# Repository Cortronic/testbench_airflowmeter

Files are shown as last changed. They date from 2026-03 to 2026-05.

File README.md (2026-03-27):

# Airflow Calibration Test Bench

<p align="left">
  
</p>  
<p align="left">
  
</p>

A high-precision, modular 125mm wind tunnel designed for the calibration and validation of airflow meters. This rig serves as the absolute reference for the [Zero-Pressure Airflow Meter project](https://github.com/Cortronic/airflowmeter).

## 1. Project Overview

The Calibration Test Bench establishes a known, stable volumetric flow rate ($m^3/h$) by drawing air through a laboratory-grade Venturi nozzle. It allows the user to set a fixed fan power and use the resulting flow as a "Golden Standard" to calibrate secondary measurement devices.

---

## 2. Hardware & Electronics

The rig uses an **ESP32-WROOM** to process environmental data and differential pressure, calculating the reference flow in real-time. To eliminate extreme static underpressure when testing restricted valves, the rig utilizes a coordinated dual-fan setup.

### Components

* **Sensor 1:** SDP810-500PA (Differential pressure across the Venturi).
* **Sensor 2:** SDP810-125PA (Differential pressure at the inlet of the Venturi).
* **Sensor 3:** BME280 (Ambient temperature, humidity, and barometric pressure).
* **Display:** 1.3" OLED (SH1106) for real-time reference data.
* **Encoder:** Rotary encode with pushbutton for speedcontrol and menu navigation.
* **Actuator:** 2 x Arctic S12038-8K High-Static Pressure Fan (12V PWM).

### ESP32 Pinout

| Component | Function | ESP32 GPIO | Notes |
| --- | --- | --- | --- |
| **I2C Bus 0** | Data / Clock | **21 / 22** | BME280, OLED, SDP810 (Venturi) |
| **I2C Bus 1** | Data / Clock | **25 / 26** | SDP810 (Balance-Pressure Sensor) |
| **Encoder** | CLK / DT / SW | **18, 19, 5** | Speed control,  Menu & Calibration |
| **PWM Pull Fan** | Speed Control | **27** | 25kHz PWM signal |
| **PWM Push Fan** | Balance Control | **14** | 25kHz PWM signal |

---

## 3. Mechanical Design

### Modular 125mm Construction

The rig is built from 125mm diameter sections, optimized for standard ventilation parts:

1. **Inlet Interface:** A 500x500mm mounting panel for airextract valves.
2. **Push Drive Section:** A high-power server fan capable of overcoming the resistance of filters and valves.
3. **Flow Conditioning:** Dual honeycomb straighteners to eliminate swirl and ensure a laminar profile before the Venturi.
4. **The Venturi Core:** A 3-part 3D-printed assembly ($D=120\text{mm}$, $d=90\text{mm}$).
5. **Pressure Sensing:** Dual piezometric (averaging) rings at the inlet and throat for stable readings.
6. **Pull Drive Section:** A high-power server fan capable of overcoming the resistance of filters and valves.
7. **Outlet Interface:** A 500x500mm mounting panel for airsupply valves.

---

## 4. Active Static Pressure Balancing
The Test Bench features an advanced "Active Balance" control loop to ensure measurement linearity regardless of inlet restriction.

* **Primary Loop (Flow Control):** The Exhaust (Pull) fan is set to a specific PWM or RPM to achieve the target flow rate.
* **Secondary Loop (Pressure Balance):** A dedicated SDP810 sensor monitors the static pressure difference between the Venturi inlet and the ambient room.
* **Active Compensation:** A PID controller adjusts the Inlet (Push) fan in real-time. If a restrictive valve causes a pressure drop, the Push fan increases power until the internal static pressure returns to 0.0 Pa (Atmospheric Neutral).

**Result:** The Venturi operates in a "Stagnation-Free" zone, eliminating the "Negative Delta-P" phenomenon and ensuring laboratory-grade accuracy even at >90% valve restriction.

---

## 5. Calibration Physics

The reference flow $Q$ is calculated using the ISO 5167 standard principles, corrected for the actual air density at the time of measurement.

### Air Density ($\rho$)

Density is calculated using the **Magnus-Tetens** formula to account for water vapor:

$$\rho = \frac{p_{dry}}{R_d \cdot T} + \frac{p_{vapor}}{R_v \cdot T}$$

### Volumetric Flow ($Q$)

$$\text{Reference } Q = 3600 \cdot C_d \cdot A_{throat} \cdot \sqrt{\frac{2 \cdot \Delta P}{\rho \cdot (1 - \beta^4)}}$$

The discharge coefficient ($C_d$) is determined during initial rig validation (typically 0.975).

---

## 6. Usage: Calibrating the Flow Meter

This rig is designed to be used in conjunction with the **Zero-Pressure Airflow Meter** interactive calibration modes.

### Calibration Workflow:

1. **Establish Reference:** Run the Test Bench fan at a fixed power (e.g., 50%) and note the reference flow (e.g., $120.0 \text{ m}^3/h$).
2. **Attach Device Under Test (DUT):** Place the Zero-Pressure Flow Meter against the rig's inlet.
3. **Zero-Compensation:** Use the Flow Meter's `Tune Zero-Comp` menu to shift its setpoint until the Test Bench returns to exactly $120.0 \text{ m}^3/h$.
4. **Flow Gain:** Use the `Tune Flow` menu to match the Flow Meter's display to the Test Bench's reference value.

### Traceability & Validation
  
The reference flow of this Test Bench is validated against a calibrated Testo 420.
1. A multi-point measurement was performed across the full PWM range of the fan.
2. The Discharge Coefficient ($C_d$) was empirically determined by comparing the Venturi $\Delta P$ to the calibrated reference flow.
3. This ensures that the Test Bench acts as a traceable "Golden Standard" for secondary devices.

---

## 7. Manufacturing Notes

* **Material:** PETG (0.2mm layer height).
* **Assembly:** Parts are flanged for easy airtight coupling. The Venturi sections are bonded with epoxy to prevent leaks at the pressure rings.
* **Precision:** The internal surface of the Venturi should be sanded or printed with high precision to maintain a consistent $C_d$.

---

## License

MIT License - Created for the open-source ventilation community.

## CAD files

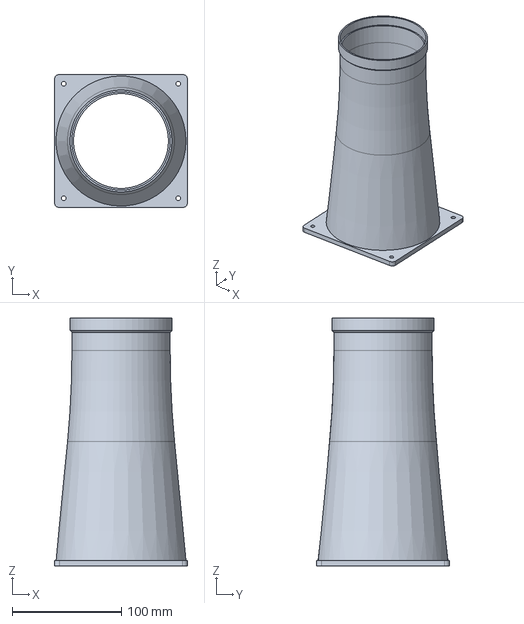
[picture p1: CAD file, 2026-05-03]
freecad/outlet120mm.FCStd
122.0 x 122.0 x 227.4 mm

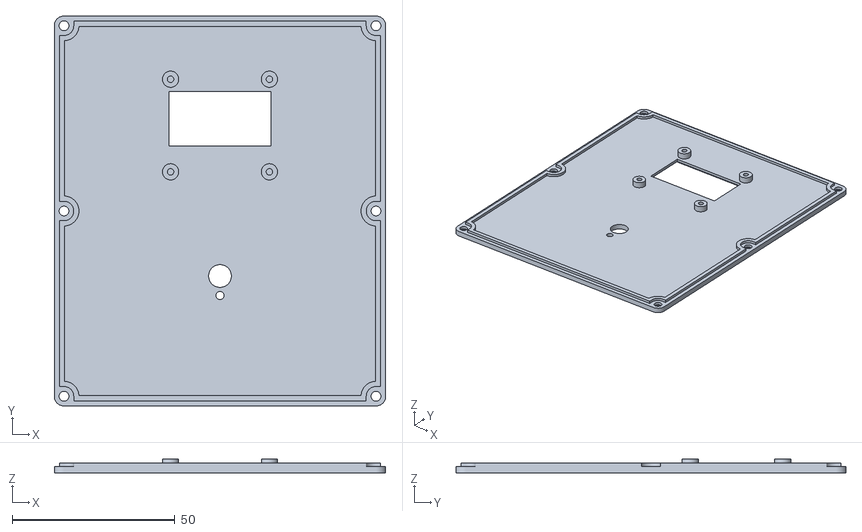
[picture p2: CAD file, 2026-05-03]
stl/case_testbench_body_lid.stl
102.0 x 120.0 x 4.30

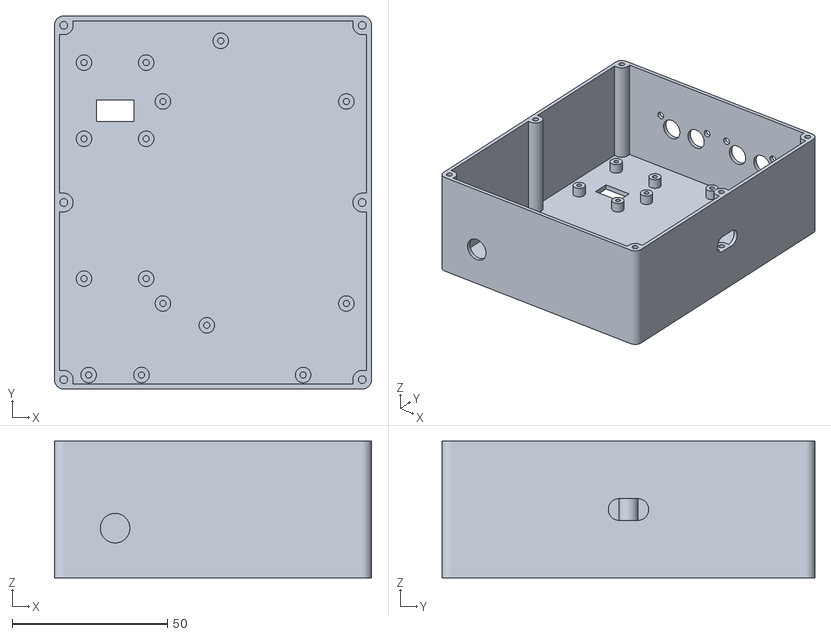
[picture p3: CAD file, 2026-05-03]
stl/case_testbench_body_case.stl
102.0 x 120.0 x 44.0

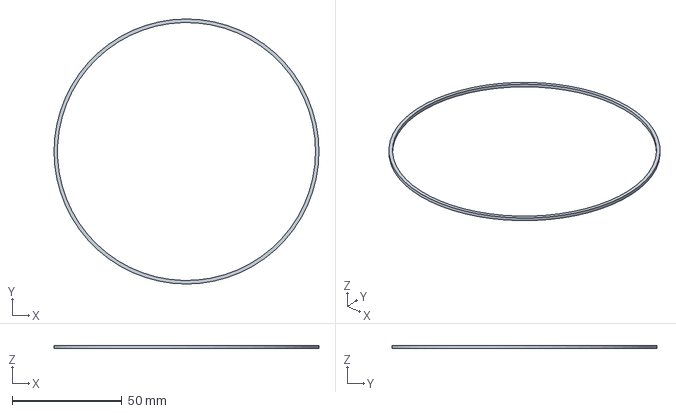
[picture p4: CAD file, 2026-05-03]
freecad/gasket.FCStd
120.8 x 120.8 x 1.40 mm

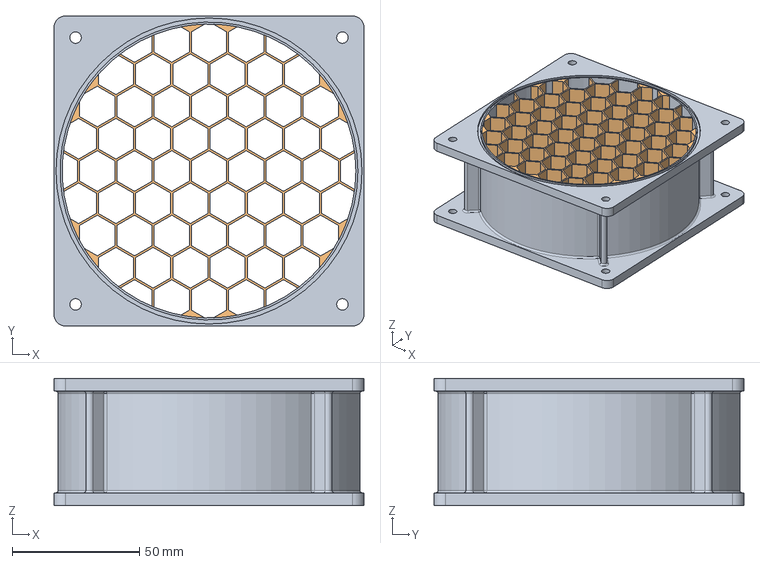
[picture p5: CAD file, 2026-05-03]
freecad/flowstraitener.FCStd
122.0 x 122.0 x 50.0 mm
BodyInlet
BodyHoneycomb

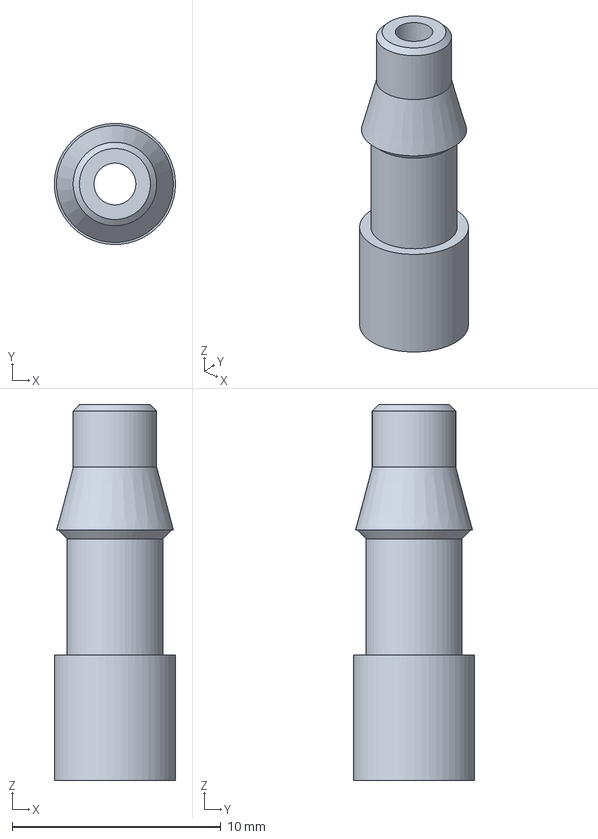
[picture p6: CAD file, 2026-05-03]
freecad/hosebarb.FCStd
5.79 x 5.80 x 18.0 mm

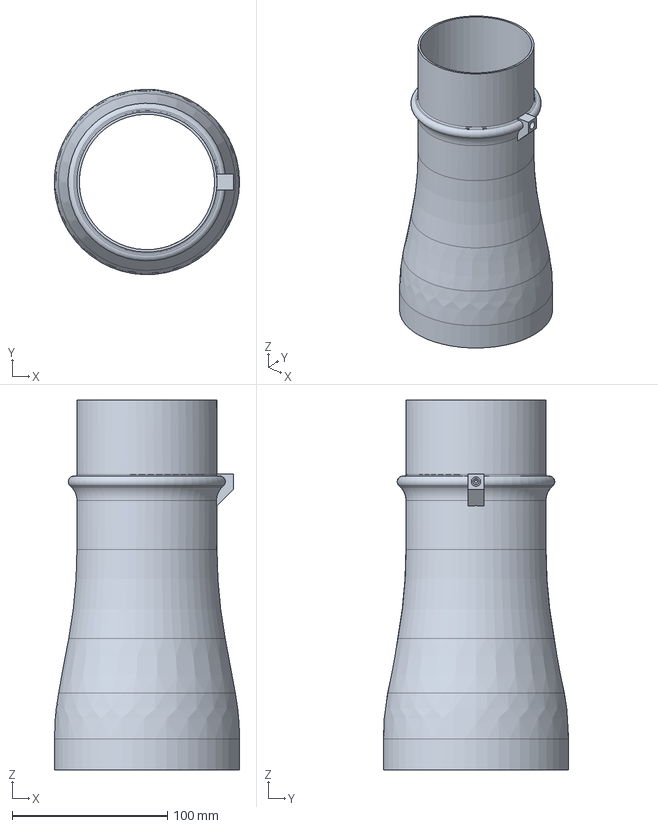
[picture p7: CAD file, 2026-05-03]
freecad/venturi120mm.FCStd
119.1 x 119.1 x 238.0 mm

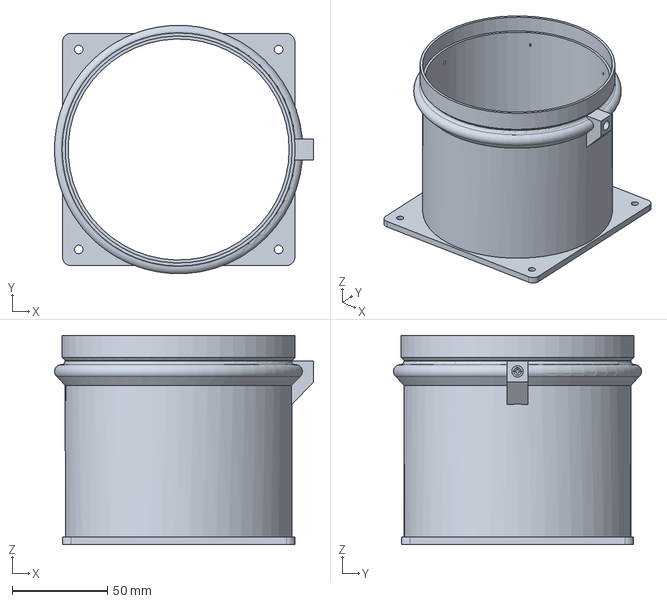
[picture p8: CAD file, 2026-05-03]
freecad/inlet120mm.FCStd
136.0 x 130.3 x 110.0 mm

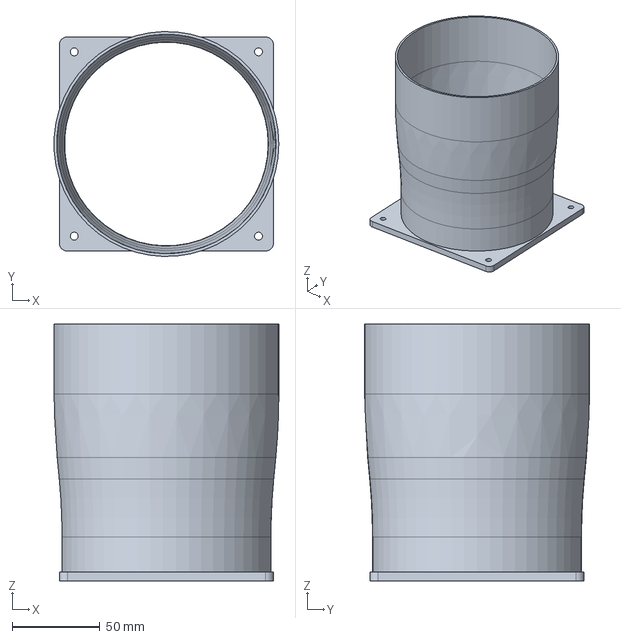
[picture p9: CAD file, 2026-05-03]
freecad/adaper120-125mm.FCStd
128.1 x 128.1 x 146.5 mm

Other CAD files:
freecad/case_testbench.FCStd
stl/adaper120-125mm.stl
stl/flowstraitener.stl
stl/gasket.stl
stl/hosebarb.stl
stl/outlet_120mm.stl

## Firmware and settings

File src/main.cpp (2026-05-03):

#include "main.h"
#include "venturi.h"
#include "fan.h"
#include "PidController.h"
#include <Arduino.h>
#include <Wire.h>
#include <Preferences.h>
#include <AiEsp32RotaryEncoder.h>
#include <AiEsp32RotaryEncoderNumberSelector.h>
#include <SensirionCore.h>
#include <SensirionI2CSdp.h>
#include <Adafruit_SH110X.h>
#include <Fonts/Picopixel.h>
#include <Adafruit_Sensor.h>
#include <Adafruit_BME280.h>
#include <Smoothed.h>

// Pin definitions
const int FAN_ON_PIN  = 32;
const int FAN_PULL_PWM_PIN = 27;
const int FAN_PUSH_PWM_PIN = 14;
const int FAN_PULL_TACHO_PIN = 34;
const int FAN_PUSH_TACHO_PIN = 35;

//I2C pin definitions
const int I2C_SDA0_PIN = 21;
const int I2C_SCL0_PIN = 22;
const int I2C_SDA1_PIN = 25;
const int I2C_SCL1_PIN = 26;

// Display
const int I2C_ADDRESS_DISPLAY = 0x3C;
const int I2C_ADDRESS_BME280  = 0x76;
const int I2C_ADDRESS_SDP810  = 0x25;

// Rotary encoder
const int ROTARY_ENCODER_A_PIN = 18;
const int ROTARY_ENCODER_B_PIN = 19;
const int ROTARY_ENCODER_BUTTON_PIN = 5;
const int ROTARY_ENCODER_STEPS = 4;

// PWM settings
const int PWM_PULL_FAN_CHAN = LEDC_CHANNEL_0;
const int PWM_PUSH_FAN_CHAN = LEDC_CHANNEL_1;
const int PWM_FREQ = 25000;    // 25 kHz frequency for computer fans
const int PWM_RESOLUTION = 10; // 10-bit resolution (0-1023)
const int PWM_DITHER_RESOLUTION = 2; // 2-bit resolution for dithering (0-3)

// tachometer
volatile uint32_t tachoFanPulseCycles;
volatile uint32_t tachoPushFanPulseCount;
volatile uint32_t tachoPullFanPulseCount;
volatile uint32_t tachoPullFanRPM = 0;
volatile uint32_t tachoPushFanRPM = 0;

// Venturi
Venturi venturi;

Fan pullFan(FAN_PULL_PWM_PIN, PWM_PULL_FAN_CHAN, PWM_FREQ, PWM_RESOLUTION, PWM_DITHER_RESOLUTION);
Fan pushFan(FAN_PUSH_PWM_PIN, PWM_PUSH_FAN_CHAN, PWM_FREQ, PWM_RESOLUTION, PWM_DITHER_RESOLUTION);

//paramaters for button
const unsigned long shortPressAfterMiliseconds = 50;   // how long short press shoud be.
                                                       // Do not set too low to avoid bouncing (false press events).
const unsigned long longPressAfterMiliseconds = 1000;  // how long long press shoud be.

AiEsp32RotaryEncoder *rotaryEncoder = new AiEsp32RotaryEncoder(ROTARY_ENCODER_A_PIN, ROTARY_ENCODER_B_PIN,
  ROTARY_ENCODER_BUTTON_PIN, -1, ROTARY_ENCODER_STEPS, false);
AiEsp32RotaryEncoderNumberSelector numberSelector = AiEsp32RotaryEncoderNumberSelector();

Preferences preferences;

Smoothed<float> balancePressure;
Smoothed<float> pressureAbsolute;
Smoothed<float> temperatureAmbient;
Smoothed<float> humidityAmbient;
Smoothed<float> calibration;

// Twee hardware I2C bussen
TwoWire I2C_A = TwoWire(0);
TwoWire I2C_B = TwoWire(1);

SensirionI2CSdp sdpVenturi;
SensirionI2CSdp sdpBalance;

// Initialize the OLED display using Wire library
// ADDRESS, SDA, SCL  -  SDA and SCL usually populate automatically
// based on your board's pins_arduino.h 
// e.g. https://github.com/esp8266/Arduino/blob/master/variants/nodemcu/pins_arduino.h
// SH1106Wire      display(I2C_ADDRESS_DISPLAY, I2C_SDA0_PIN, I2C_SCL0_PIN, GEOMETRY_128_64);
Adafruit_SH1106G display(128, 64, &I2C_A);
Adafruit_BME280  bme280;     // I2C

hw_timer_t *timer0 = nullptr;
volatile bool ms20_passed = false;

FollowFanType followFanType = FOLLOW_PULL_FAN;
ModeType modeType = MT_OPERATION;
PidTuneType pidTuneType = PID_TUNE_NONE;
OperatingMode operatingMode = OM_SPEED_PULL_FAN;
VenturiConstantsType venturiConstantsType = VENTURI_CONSTANTS_SET_NONE;


double minPidFlowInput = NAN;
double maxPidFlowInput = NAN;
double minPidFlowFilteredInput = NAN;
double maxPidFlowFilteredInput = NAN;
double minPidFlowOutput = NAN;
double maxPidFlowOutput = NAN;

double outputMasterFan = 0.0;
double KpFlow=2, KiFlow=0, KdFlow=0, flowOutputTrendLimit=0.5;
double flowAlpha=0.2, flowBeta=0.02;
PidController pidFlow(KpFlow, KiFlow, KdFlow, 0.02, 0.0, 100.0);

double minPidBalanceInput = NAN;
double maxPidBalanceInput = NAN;
double minPidBalanceFilteredInput = NAN;
double maxPidBalanceFilteredInput = NAN;
double minPidBalanceOutput = NAN;
double maxPidBalanceOutput = NAN;

double outputSlaveFan = 0.0;
double KpBalance = 6, KiBalance = 3, KdBalance = 0, balanceOutputTrendLimit = 0.5;
double balanceAlpha = 0.2, balanceBeta = 0.02;
PidController pidBalance(KpBalance, KiBalance, KdBalance, 0.02, 0.0, 100.0);

float offsetVenturiPressure = 0.0;
float offsetBalancePressure = 0.0;
float lastEncoderOperationValue = 0.0;

static void  setupTachometers();
static void  setupTimer0();
static void  readPressureSensors();
static void  loadPreferences();
static void  setupRotaryEncoder();
static void  setMasterFan(FollowFanType type);
static void  setMasterFanSpeedPercent(float speed);
static void  setSlaveFanSpeedPercent(float speed);
static void  setOperationMode(OperatingMode mode);
static void  initDisplay();
static void  loopRotaryEncoder();
static void  displayMeasurements();
static void  displaySelectMode(ModeType);
static void  displaySelectOperationMode(OperatingMode mode);
static void  displayTextNumber(const char *txt, float);
static void  displayAdjustSensorOffsets(const char *sensor);
static void  displayAdjustSensorOffsetsProgress(int16_t progress);
static void  displaySelectTunePID(PidTuneType type);
static void  displaySelectVenturiConstants(VenturiConstantsType type);
static void  initBME280();
static void  initSDP(SensirionI2CSdp&, TwoWire&);
static void  drawString(int16_t x, int16_t y, const String &text);
//////////////////////////////////////////////////////////////////////////

void setup() {

  Serial.begin(115200);

  Serial.println("\ntestbench_airflowmeter is starting up...");

  // prefent fan from starting up
  pinMode(FAN_ON_PIN, OUTPUT);
  digitalWrite(FAN_ON_PIN, LOW);

  //setupTachometers();

  // load preferences (calibration and PID parameters)
  loadPreferences();

  // setup RotaryEncoder
  setupRotaryEncoder();

  // Setup Fans
  Serial.println("Setup Fans");
  pullFan.begin();
  pushFan.begin();

  // set initial fan speeds to zero
  setMasterFanSpeedPercent(0);
  setSlaveFanSpeedPercent(0);
  delay(1000);

  // Start both I2C busses
  I2C_A.begin(I2C_SDA0_PIN, I2C_SCL0_PIN, 700000);   // SDA, SCL
  I2C_B.begin(I2C_SDA1_PIN, I2C_SCL1_PIN, 100000);

  Serial.println("Setup Display");
  initDisplay();
  delay(500);
  Serial.println("Setup BME280");
  initBME280();
  delay(500);
  Serial.println("Setup SDP810 Venturi");
  initSDP(sdpVenturi, I2C_A);
  delay(500);
  Serial.println("Setup SDP810 Balance");
  initSDP(sdpBalance, I2C_B);
  delay(500);

  Serial.println("setup smoothed average.");
  balancePressure.begin(SMOOTHED_EXPONENTIAL, 10);
  calibration.begin(SMOOTHED_AVERAGE, 200);
  pressureAbsolute.begin(SMOOTHED_AVERAGE, 40);
  humidityAmbient.begin(SMOOTHED_AVERAGE, 40);
  temperatureAmbient.begin(SMOOTHED_AVERAGE, 40);
  delay(500);

  // initialize the Flow PID variables
  Serial.println("turn the PID Flow on.");
  pidFlow.setTunings(KpFlow, KiFlow, KdFlow);
  pidFlow.setOutputLimits(0, 100.0, flowOutputTrendLimit); // Output will be in percentage of max PWM (0-100%)
  pidFlow.setSampleTime(0.02); // 20 ms sample time
  pidFlow.setAlpha(flowAlpha);
  pidFlow.setBeta(flowBeta);
  pidFlow.setOutputTrendLimit(flowOutputTrendLimit);
  delay(500);

  // initialize the Balance PID variables
  Serial.println("turn the PID Balance on.");
  pidBalance.setTunings(KpBalance, KiBalance, KdBalance);
  pidBalance.setOutputLimits(0, 100, balanceOutputTrendLimit); // Output will be in percentage of max PWM (0-100%)
  pidBalance.setSampleTime(0.02); // 20 ms sample time
  pidBalance.setAlpha(balanceAlpha); // Set the alpha parameter for the exponential moving average filter
  pidBalance.setBeta(balanceBeta); // Set the beta parameter for trend estimation
  pidBalance.setOutputTrendLimit(balanceOutputTrendLimit); // Set the trend limit to prevent excessive influence of the trend on the output
  delay(500);

  // get initial measurements from the sensors to populate the smoothed averages and the venturi flow calculation
  bme280.takeForcedMeasurement();
  pressureAbsolute.add(bme280.readPressure());
  temperatureAmbient.add(bme280.readTemperature());
  humidityAmbient.add(bme280.readHumidity());
  venturi.setRho(pressureAbsolute.get(), temperatureAmbient.get(), humidityAmbient.get());

  // Setup timer interrupt for tachometer reading, flow and balance pressure PID loops
  Serial.print("Setup timer interrupt\n");
  setupTimer0();
  delay(500);
  
  Serial.print("\n Setup done...\n\n");
  delay(500);
}
//////////////////////////////////////////////////////////////////////////

void loop() {
  static uint32_t loopcnt = 0;
  static uint32_t last_millis = 0;
  uint32_t now = millis();
  
  // repeated calls are needed to avoid that the display slows down the loop and causes the PID to underperform
  readPressureSensors();

  loopRotaryEncoder();

  // every 100ms
  if (now >= last_millis + 100) {
    last_millis = now;

    readPressureSensors();
    
    // every second
    if (loopcnt % 10 == 0) {

      // Only needed in forced mode! In normal mode, you can remove the next line.
      bme280.takeForcedMeasurement(); // has no effect in normal mode
      readPressureSensors();

      // get the measurements from the BME280
      pressureAbsolute.add(bme280.readPressure()); // Pa
      readPressureSensors();
      temperatureAmbient.add(bme280.readTemperature()); // °C
      readPressureSensors();
      humidityAmbient.add(bme280.readHumidity());
      readPressureSensors();
      
      /* Serial.printf("Flow: %.1f m3/s\n", venturi.getLastFlow());
      Serial.printf("Dutycycle Masterfan: %.1f%%\n", outputMasterFan);
      Serial.printf("Balance Pressure: %.1f Pa\n", balancePressure.get());
      Serial.printf("Dutycycle Slavefan: %.1f%%\n", outputPidBalanceFan);
      readPressureSensors(); // */
    }
    
    // every second
    if (loopcnt % 10 == 0) {
      if (!isnan(minPidFlowFilteredInput)) {
        Serial.printf(
          "flow: %.1fm3/h, %.1fm3/h, %.1fm3/s, %.1fm3/s, %.1f%%, %.1f%%  \r",
          minPidFlowInput,
          maxPidFlowInput,
          minPidFlowFilteredInput,
          maxPidFlowFilteredInput,
          minPidFlowOutput,
          maxPidFlowOutput
        );
        minPidFlowInput = NAN;
        maxPidFlowInput = NAN;
        minPidFlowFilteredInput = NAN;
        maxPidFlowFilteredInput = NAN;
        minPidFlowOutput = NAN;
        maxPidFlowOutput = NAN;
        readPressureSensors();
      }
      if (!isnan(minPidBalanceFilteredInput)) {
        Serial.printf(
          "balance: %.1fpa, %.1fpa, %.2fpa, %.2fpa, %.1f%%, %.1f%%  \r",
          minPidBalanceInput,
          maxPidBalanceInput,
          minPidBalanceFilteredInput,
          maxPidBalanceFilteredInput,
          minPidBalanceOutput,
          maxPidBalanceOutput
        );
        minPidBalanceInput = NAN;
        maxPidBalanceInput = NAN;
        minPidBalanceFilteredInput = NAN;
        maxPidBalanceFilteredInput = NAN;
        minPidBalanceOutput = NAN;
        maxPidBalanceOutput = NAN;
        readPressureSensors();
      }
    }

    // every 2 seconds
    if (loopcnt % 20 == 0) {
      if (modeType == MT_OPERATION 
          || modeType == MT_CAL_FLOW
          || pidTuneType != PID_TUNE_NONE
          || venturiConstantsType != VENTURI_CONSTANTS_SET_NONE
      ) {
        displayMeasurements(); // 42ms
      }
    }

    // every minute
    if (loopcnt % 600 == 0) {
       venturi.setRho(pressureAbsolute.get(), temperatureAmbient.get(), humidityAmbient.get());
       readPressureSensors();
    }

    ++loopcnt;
  }
}
//////////////////////////////////////////////////////////////////////////

// Interrupt Service Routine (ISR)
// IRAM_ATTR places the function in RAM for faster execution
void IRAM_ATTR Timer0_ISR() {
  ms20_passed = true;
  
  pushFan.handleDither(); // Call the handleDither method for the push fan to manage PWM dithering
  pullFan.handleDither(); // Call the handleDither method for the pull fan to manage PWM dithering
  
  // Handle tachometer pulse counting and RPM calculation
  if (--tachoFanPulseCycles == 0) {
    tachoPullFanRPM = tachoPullFanPulseCount * 10;
    tachoPullFanPulseCount = 0;
    tachoPushFanRPM = tachoPushFanPulseCount * 10;
    tachoPushFanPulseCount = 0;
    tachoFanPulseCycles = 150;
  }
}
//////////////////////////////////////////////////////////////////////////

void IRAM_ATTR readEncoder_ISR() {
    rotaryEncoder->readEncoder_ISR();
}
//////////////////////////////////////////////////////////////////////////

void IRAM_ATTR readButton_ISR() {
    rotaryEncoder->readButton_ISR();
}
//////////////////////////////////////////////////////////////////////////

void IRAM_ATTR tachoPullFanPulseCount_ISR() {
  tachoPullFanPulseCount++;
}
//////////////////////////////////////////////////////////////////////////

void IRAM_ATTR tachoPushFanPulseCount_ISR() {
  tachoPushFanPulseCount++;
}
//////////////////////////////////////////////////////////////////////////

static void setupTachometers() {
  tachoPushFanPulseCount = 0;
  tachoPullFanPulseCount = 0;
  tachoFanPulseCycles = 150;
  pinMode(FAN_PULL_TACHO_PIN, INPUT_PULLUP); // GPIO 34
  attachInterrupt(digitalPinToInterrupt(FAN_PULL_TACHO_PIN), tachoPullFanPulseCount_ISR, FALLING);
  pinMode(FAN_PUSH_TACHO_PIN, INPUT_PULLUP); // GPIO 35
  attachInterrupt(digitalPinToInterrupt(FAN_PUSH_TACHO_PIN), tachoPushFanPulseCount_ISR, FALLING);
}
//////////////////////////////////////////////////////////////////////////

static void setupTimer0() {
  // 1. Initialize timer
  //timerBegin(timer_number, divider, countUp)
  // Prescaler 80: 80MHz / 80 = 1MHz (1 microsecond per tick)
  timer0 = timerBegin(0, 80, true);

  // 2. Attach the ISR function
  timerAttachInterrupt(timer0, &Timer0_ISR, true);

  // 3. Set alarm to fire every 20000 ticks (20000 us = 20ms)
  // timerAlarmWrite(timer, microseconds, autoreload)
  timerAlarmWrite(timer0, 20000, true);

  // 4. Enable the alarm
  timerAlarmEnable(timer0);
}
//////////////////////////////////////////////////////////////////////////

static void updateStatisticsPidFlow(float flow) {
  if (isnan(minPidFlowInput) || flow < minPidFlowInput) {
    minPidFlowInput = flow;
  }
  if (isnan(maxPidFlowInput) || flow > maxPidFlowInput) {
    maxPidFlowInput = flow;
  }
  if (isnan(minPidFlowFilteredInput) || pidFlow.getFilteredInput() < minPidFlowFilteredInput) {
    minPidFlowFilteredInput = pidFlow.getFilteredInput();
  }
  if (isnan(maxPidFlowFilteredInput) || pidFlow.getFilteredInput() > maxPidFlowFilteredInput) {
    maxPidFlowFilteredInput = pidFlow.getFilteredInput();
  }
  if (isnan(minPidFlowOutput) || outputMasterFan < minPidFlowOutput) {
    minPidFlowOutput = outputMasterFan;
  }
  if (isnan(maxPidFlowOutput) || outputMasterFan > maxPidFlowOutput) {
    maxPidFlowOutput = outputMasterFan;
  }
}
//////////////////////////////////////////////////////////////////////////

static void updateStatisticsPidBalance(float differentialPressure) {
  if (isnan(minPidBalanceInput) || differentialPressure < minPidBalanceInput) {
    minPidBalanceInput = differentialPressure;
  }
  if (isnan(maxPidBalanceInput) || differentialPressure > maxPidBalanceInput) {
    maxPidBalanceInput = differentialPressure;
  }
  if (isnan(minPidBalanceFilteredInput) || pidBalance.getFilteredInput() < minPidBalanceFilteredInput) {
    minPidBalanceFilteredInput = pidBalance.getFilteredInput();
  }
  if (isnan(maxPidBalanceFilteredInput) || pidBalance.getFilteredInput() > maxPidBalanceFilteredInput) {
    maxPidBalanceFilteredInput = pidBalance.getFilteredInput();
  }
  if (isnan(minPidBalanceOutput) || outputSlaveFan < minPidBalanceOutput) {
    minPidBalanceOutput = outputSlaveFan;
  }
  if (isnan(maxPidBalanceOutput) || outputSlaveFan > maxPidBalanceOutput) {
    maxPidBalanceOutput = outputSlaveFan;
  }
}
//////////////////////////////////////////////////////////////////////////

static void readPressureSensors() {
  
  if (ms20_passed == true) {
    ms20_passed = false;
    float differentialPressure, temperature;

    // 2 ms time to read
    uint16_t error = sdpVenturi.readMeasurement(differentialPressure, temperature);
    if (error) {
      Serial.print("Error trying to execute readMeasurement from Venturi Pressure sensor\n");
      venturi.update(0.0);
    } else {
      differentialPressure -= offsetVenturiPressure;
      float flowVenturi = venturi.update(differentialPressure);
      if (modeType != MT_ADJUST_OFFSETS) {
        if (operatingMode == OM_FLOW_PULL_FAN || operatingMode == OM_FLOW_PUSH_FAN) {
          outputMasterFan = pidFlow.update(flowVenturi);
          setMasterFanSpeedPercent(outputMasterFan);
          if (modeType == MT_TUNE_PID_FLOW) {
            updateStatisticsPidFlow(flowVenturi);
          }
        }
      }
    }

    error = sdpBalance.readMeasurement(differentialPressure, temperature);
    if (error) {
      Serial.print("Error trying to execute readMeasurement from Balance Pressure sensor\n");
      balancePressure.add(0.0);
    } else {
      differentialPressure -= offsetBalancePressure;
      balancePressure.add(differentialPressure);
      outputSlaveFan = pidBalance.update(differentialPressure);
      setSlaveFanSpeedPercent(outputSlaveFan);
      if (modeType == MT_TUNE_PID_BALANCE) {
        updateStatisticsPidBalance(differentialPressure);
      }
    }
  }
}
//////////////////////////////////////////////////////////////////////////

static float getFloat(const char* key, float value = NAN) {
  float f;
  preferences.begin("testbench", false);
  f = preferences.getFloat(key, value);
  preferences.end();
  return f == NAN ? 0.0 : f;
}
//////////////////////////////////////////////////////////////////////////

static void saveFloat(const char* key, float value) {
  preferences.begin("testbench", false);
  preferences.putFloat(key, value);
  preferences.end();
}
//////////////////////////////////////////////////////////////////////////

static void loadPreferences() {
  preferences.begin("testbench", true);

  float inletDiameter = preferences.getFloat(KEY_VENTURI_INLET_DIAMETER, 0.116);
  float throatDiameter = preferences.getFloat(KEY_VENTURI_THROAT_DIAMETER, 0.087);
  float dischargeCoefficient = preferences.getFloat(KEY_VENTURI_CD, 0.975);
  venturi.begin(inletDiameter, throatDiameter, dischargeCoefficient);
  venturi.setSmoothedFlowFactor(preferences.getFloat(KEY_VENTURI_SMOOTHING_FACTOR, 0.02));

  offsetBalancePressure = preferences.getFloat(KEY_OFFSET_BALANCE_PRESSURE_SENSOR, 0.0);
  offsetVenturiPressure = preferences.getFloat(KEY_OFFSET_VENTURI_PRESSURE_SENSOR, 0.0);
  KpFlow =  preferences.getFloat(KEY_KP_FLOW, KpFlow);
  KiFlow =  preferences.getFloat(KEY_KI_FLOW, KiFlow);
  KdFlow =  preferences.getFloat(KEY_KD_FLOW, KdFlow);
  flowAlpha = preferences.getFloat(KEY_ALPHA_FLOW, flowAlpha);
  flowBeta = preferences.getFloat(KEY_BETA_FLOW, flowBeta);
  flowOutputTrendLimit = preferences.getFloat(KEY_TREND_LIMIT_FLOW, flowOutputTrendLimit);
  KpBalance = preferences.getFloat(KEY_KP_BALANCE, KpBalance);
  KiBalance = preferences.getFloat(KEY_KI_BALANCE, KiBalance);
  KdBalance = preferences.getFloat(KEY_KD_BALANCE, KdBalance);
  balanceAlpha = preferences.getFloat(KEY_BALANCE_ALPHA, balanceAlpha);
  balanceBeta = preferences.getFloat(KEY_BALANCE_BETA, balanceBeta);
  balanceOutputTrendLimit = preferences.getFloat(KEY_BALANCE_TREND_LIMIT, balanceOutputTrendLimit);

  preferences.end();
}
//////////////////////////////////////////////////////////////////////////

static void setupRotaryEncoder() {
  rotaryEncoder->begin();
  rotaryEncoder->setup(&readEncoder_ISR, &readButton_ISR);
  numberSelector.attachEncoder(rotaryEncoder);

  // numberSelector.setRange parameters:
  float minValue = 0.0;        // set minimum value for example -12.0
  float maxValue = 100.0;      // set maxinum value for example 12.0
  float step = 0.1;            // set step increment, default 1, can be smaller steps like 0.5 or 10
  bool cycleValues = false;    // set true only if you want going to miminum value after maximum 
  unsigned int decimals = 1;   // set precision - how many decimal places you want, default is 0
  numberSelector.setRange(minValue, maxValue,  step, cycleValues, decimals);
  numberSelector.setValue(0);  // sets initial value
}
//////////////////////////////////////////////////////////////////////////

static void setPullFanSpeed(uint32_t speed) {
  static uint32_t lastspeed = 0xFFFFFFFF;

  if (lastspeed != speed) {
    pullFan.setSpeed(speed);
    if (followFanType == FOLLOW_PULL_FAN) {
      if (speed == 0) {
        digitalWrite(FAN_ON_PIN, LOW);
      } else if (lastspeed == 0) {
        digitalWrite(FAN_ON_PIN, HIGH);
      }
      lastspeed = speed;
    } else {
      lastspeed = 0xFFFFFFFF;
    }
  }
} 
//////////////////////////////////////////////////////////////////////////

static void setPullFanSpeedPercent(float percent) {
  uint16_t speed = (uint16_t)(percent * pullFan.getMaxSpeed() / 100.0);
  setPullFanSpeed(speed);
}
//////////////////////////////////////////////////////////////////////////

static void setPushFanSpeed(uint32_t speed) {
  static uint32_t lastspeed = 0xFFFFFFFF;

  if (lastspeed != speed) {
    pushFan.setSpeed(speed);
    if (followFanType == FOLLOW_PUSH_FAN) {
      if (speed == 0) {
        digitalWrite(FAN_ON_PIN, LOW);
      } else if (lastspeed == 0) {
        digitalWrite(FAN_ON_PIN, HIGH);
      }
      lastspeed = speed;
    } else {
      lastspeed = 0xFFFFFFFF;
    }
 }
} 
//////////////////////////////////////////////////////////////////////////

static void setPushFanSpeedPercent(float percent) {
  uint16_t speed = (uint16_t)(percent * pushFan.getMaxSpeed() / 100.0);
  setPushFanSpeed(speed);
}
//////////////////////////////////////////////////////////////////////////

static void setMasterFanSpeed(uint32_t speed) {
  if (followFanType == FOLLOW_PULL_FAN) {
    setPullFanSpeed(speed);
  } else {
    setPushFanSpeed(speed);
  }
}
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

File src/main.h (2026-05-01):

typedef enum {
  MT_SELECT = 0,
  MT_OPERATION = 1,
  MT_SELECT_OPERATION = 2,
  MT_CAL_FLOW = 3,
  MT_TUNE_PID_FLOW = 4,
  MT_TUNE_PID_BALANCE = 5,
  MT_ADJUST_OFFSETS = 6,
  MT_SET_VENTURI_CONSTANTS = 7,
} ModeType;
extern ModeType modeType;

typedef enum {
  FOLLOW_PULL_FAN = 0,
  FOLLOW_PUSH_FAN = 1,
} FollowFanType;
extern FollowFanType followFanType;

typedef enum {
  OM_SPEED_PULL_FAN = 0,
  OM_SPEED_PUSH_FAN = 1,
  OM_FLOW_PULL_FAN = 2,
  OM_FLOW_PUSH_FAN = 3,
} OperatingMode;
extern OperatingMode operatingMode;

typedef enum {
  PID_TUNE_NONE = 0,
  PID_TUNE_P = 1,
  PID_TUNE_I = 2,
  PID_TUNE_D = 3,
  PID_TUNE_ALPHA = 4,
  PID_TUNE_BETA = 5,
  PID_TUNE_TREND_LIMIT = 6,
} PidTuneType;
extern PidTuneType pidTuneType;

typedef enum {
  VENTURI_CONSTANTS_SET_NONE = 0,
  VENTURI_CONSTANTS_SET_DIA_INLET = 1,
  VENTURI_CONSTANTS_SET_DIA_THROAT = 2,
  VENTURI_CONSTANTS_SET_SMOOTHING_FACTOR = 3,
} VenturiConstantsType;
extern VenturiConstantsType venturiConstantsType;

// Keys for saving settings in non-volatile storage
#define KEY_VENTURI_INLET_DIAMETER "inletDia"
#define KEY_VENTURI_THROAT_DIAMETER "throadDia"
#define KEY_VENTURI_CD "Cd"
#define KEY_VENTURI_SMOOTHING_FACTOR "smoothFactor"
#define KEY_OFFSET_BALANCE_PRESSURE_SENSOR "offsetBalance"
#define KEY_OFFSET_VENTURI_PRESSURE_SENSOR "offsetVenturi"
#define KEY_KP_FLOW "KpFlow"
#define KEY_KI_FLOW "KiFlow"
#define KEY_KD_FLOW "KdFlow"
#define KEY_ALPHA_FLOW "flowAlpha"
#define KEY_BETA_FLOW "flowBeta"
#define KEY_DAMPING_FLOW "flowDamping"
#define KEY_TREND_LIMIT_FLOW "flowTrendLimit"
#define KEY_KP_BALANCE "KpBalance"
#define KEY_KI_BALANCE "KiBalance"
#define KEY_KD_BALANCE "KdBalance"
#define KEY_BALANCE_ALPHA "balanceAlpha"
#define KEY_BALANCE_BETA "balanceBeta"
#define KEY_BALANCE_DAMPING "balanceDamping"
#define KEY_BALANCE_TREND_LIMIT "balanceTrendLim"

// PID controller parameters
#define PID_KP_MIN 0.0
#define PID_KP_MAX 50.0
#define PID_KP_STEP 0.01
#define PID_KP_DECIMALS 2
#define PID_KI_MIN 0.0
#define PID_KI_MAX 50.0
#define PID_KI_STEP 0.01
#define PID_KI_DECIMALS 2
#define PID_KD_MIN 0.0
#define PID_KD_MAX 50.0
#define PID_KD_STEP 0.01
#define PID_KD_DECIMALS 2
#define ALPHA_MIN 0.0
#define ALPHA_MAX 1.0
#define ALPHA_STEP 0.01
#define ALPHA_DECIMALS 2
#define BETA_MIN 0.01
#define BETA_MAX 1.0
#define BETA_STEP 0.01
#define BETA_DECIMALS 2
#define TREND_LIMIT_MIN 0.01
#define TREND_LIMIT_MAX 10.0
#define TREND_LIMIT_STEP 0.01
#define TREND_LIMIT_DECIMALS 2

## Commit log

2026-02-21 Pid tunings implemeted
2026-02-22 readin tachometer fan
2026-02-22 Fix display function to use snprintf for formatting RPM output
    [main.cpp]
2026-02-22 Fix FAN_TACHO_PIN definition and update pinMode in setup
    [main.cpp]
2026-03-06 Update README with project details and add images; modify platformio.ini for COM port; fix pulse cycle reset in main.cpp
    [main.cpp]
2026-03-06 Update README images and correct encoder pin definitions
2026-03-06 Enhance project description with hyperlink
    Added a hyperlink to the Zero-Pressure Airflow Meter project for reference.
2026-03-15 Refactor fan control and sensor handling; update README with hardware details and calibration methods
2026-03-26 A push fan has been added to increase accuracy
2026-04-04 Add case for MT_ADJUST_OFFSETS in rotary encoder loop to handle calibration progress
2026-04-15 Refactor fan control implementation and update operation modes
2026-04-16 Fix parameter order in venturi.setRho calls for accurate calculations
    [main.cpp]
2026-04-24 Refactor Venturi flow calculations and add Double Exponential Filter implementation
2026-04-27 Create new PID classes for increased stability
    [main.cpp, main.h]
2026-04-27 Remove unnecessary pid.h include from main.cpp
2026-04-28 Refactor Venturi class to add getLastFlow method and update main.cpp for improved flow measurement handling
2026-04-28 Refactor Venturi class to rename loop method to update and change return type for improved flow calculation
2026-04-28 Update PID sample time to 20 ms and adjust related variables for improved performance
2026-04-29 Add debug output for balance pressure and slave fan speed in readPressureSensors function
2026-04-29 Fix balance pressure calculation and update slave fan speed output in readPressureSensors function
    [main.cpp]
2026-04-29 Enhance pressure sensor readings by tracking min/max values for balance pressure and fan output in loop function
2026-04-30 Add output trend limit parameter to setOutputLimits method and implement trend clamping in PID controller
2026-05-01 Refactor PidController to include low-pass filtering and error scaling; update main to remove damping and trend limit parameters
    [main.cpp, main.h]
2026-05-02 Remove DoubleExponentialFilter implementation and update PidController to use filtered input for improved performance and clarity
2026-05-03 Add STL and Freecad files
    [adaper120-125mm.FCStd, adaper120-125mm.stl, case_testbench.FCStd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]
